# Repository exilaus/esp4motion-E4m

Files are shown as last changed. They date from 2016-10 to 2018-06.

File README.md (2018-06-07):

# esp4motion-E4m
killed

go to helping :
https://github.com/ryannining/karyacontroller

regards

old info.

This project want use D1 mini as basilar brain for Plotters lasercut cnc 3d printers.
currently in wip based from marginallyclever code portin on esp by Misan 

project currently managed by:
-Misan (Miguel sanchez)
-Exilaus (mauro manco)
-Darkberg (alex)

:) first preview set of board ordered....soon some news

Some info on board:
https://docs.google.com/presentation/d/1Ur_RV33AqiUAMNY1md2GBHKGxP4hxiyhX0XLN1OoxBo/edit?usp=sharing

First test of Misan
https://www.youtube.com/watch?v=iX7SKLwmQTw

For any info you can contact myself on G+ :) after test basic function on board need more coder :)

enjoy

Lib for arduino:

- https://github.com/tzapu/WiFiManager
- https://github.com/hibikiledo/Adafruit-MCP23017-Arduino-Library

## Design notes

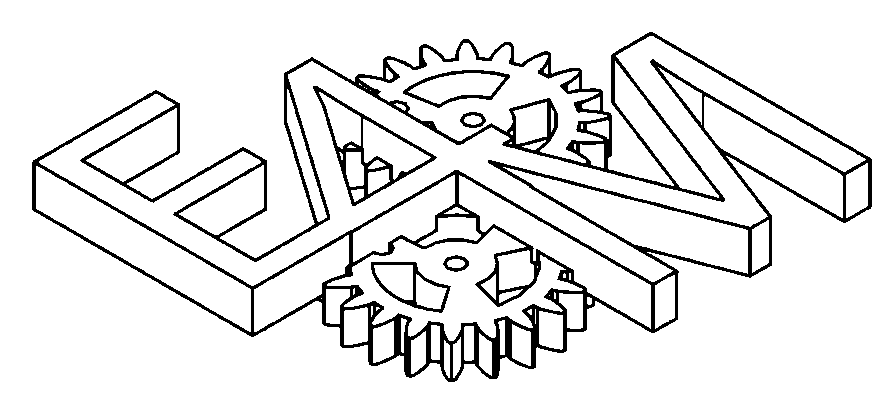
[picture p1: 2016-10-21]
board/e4m.bmp

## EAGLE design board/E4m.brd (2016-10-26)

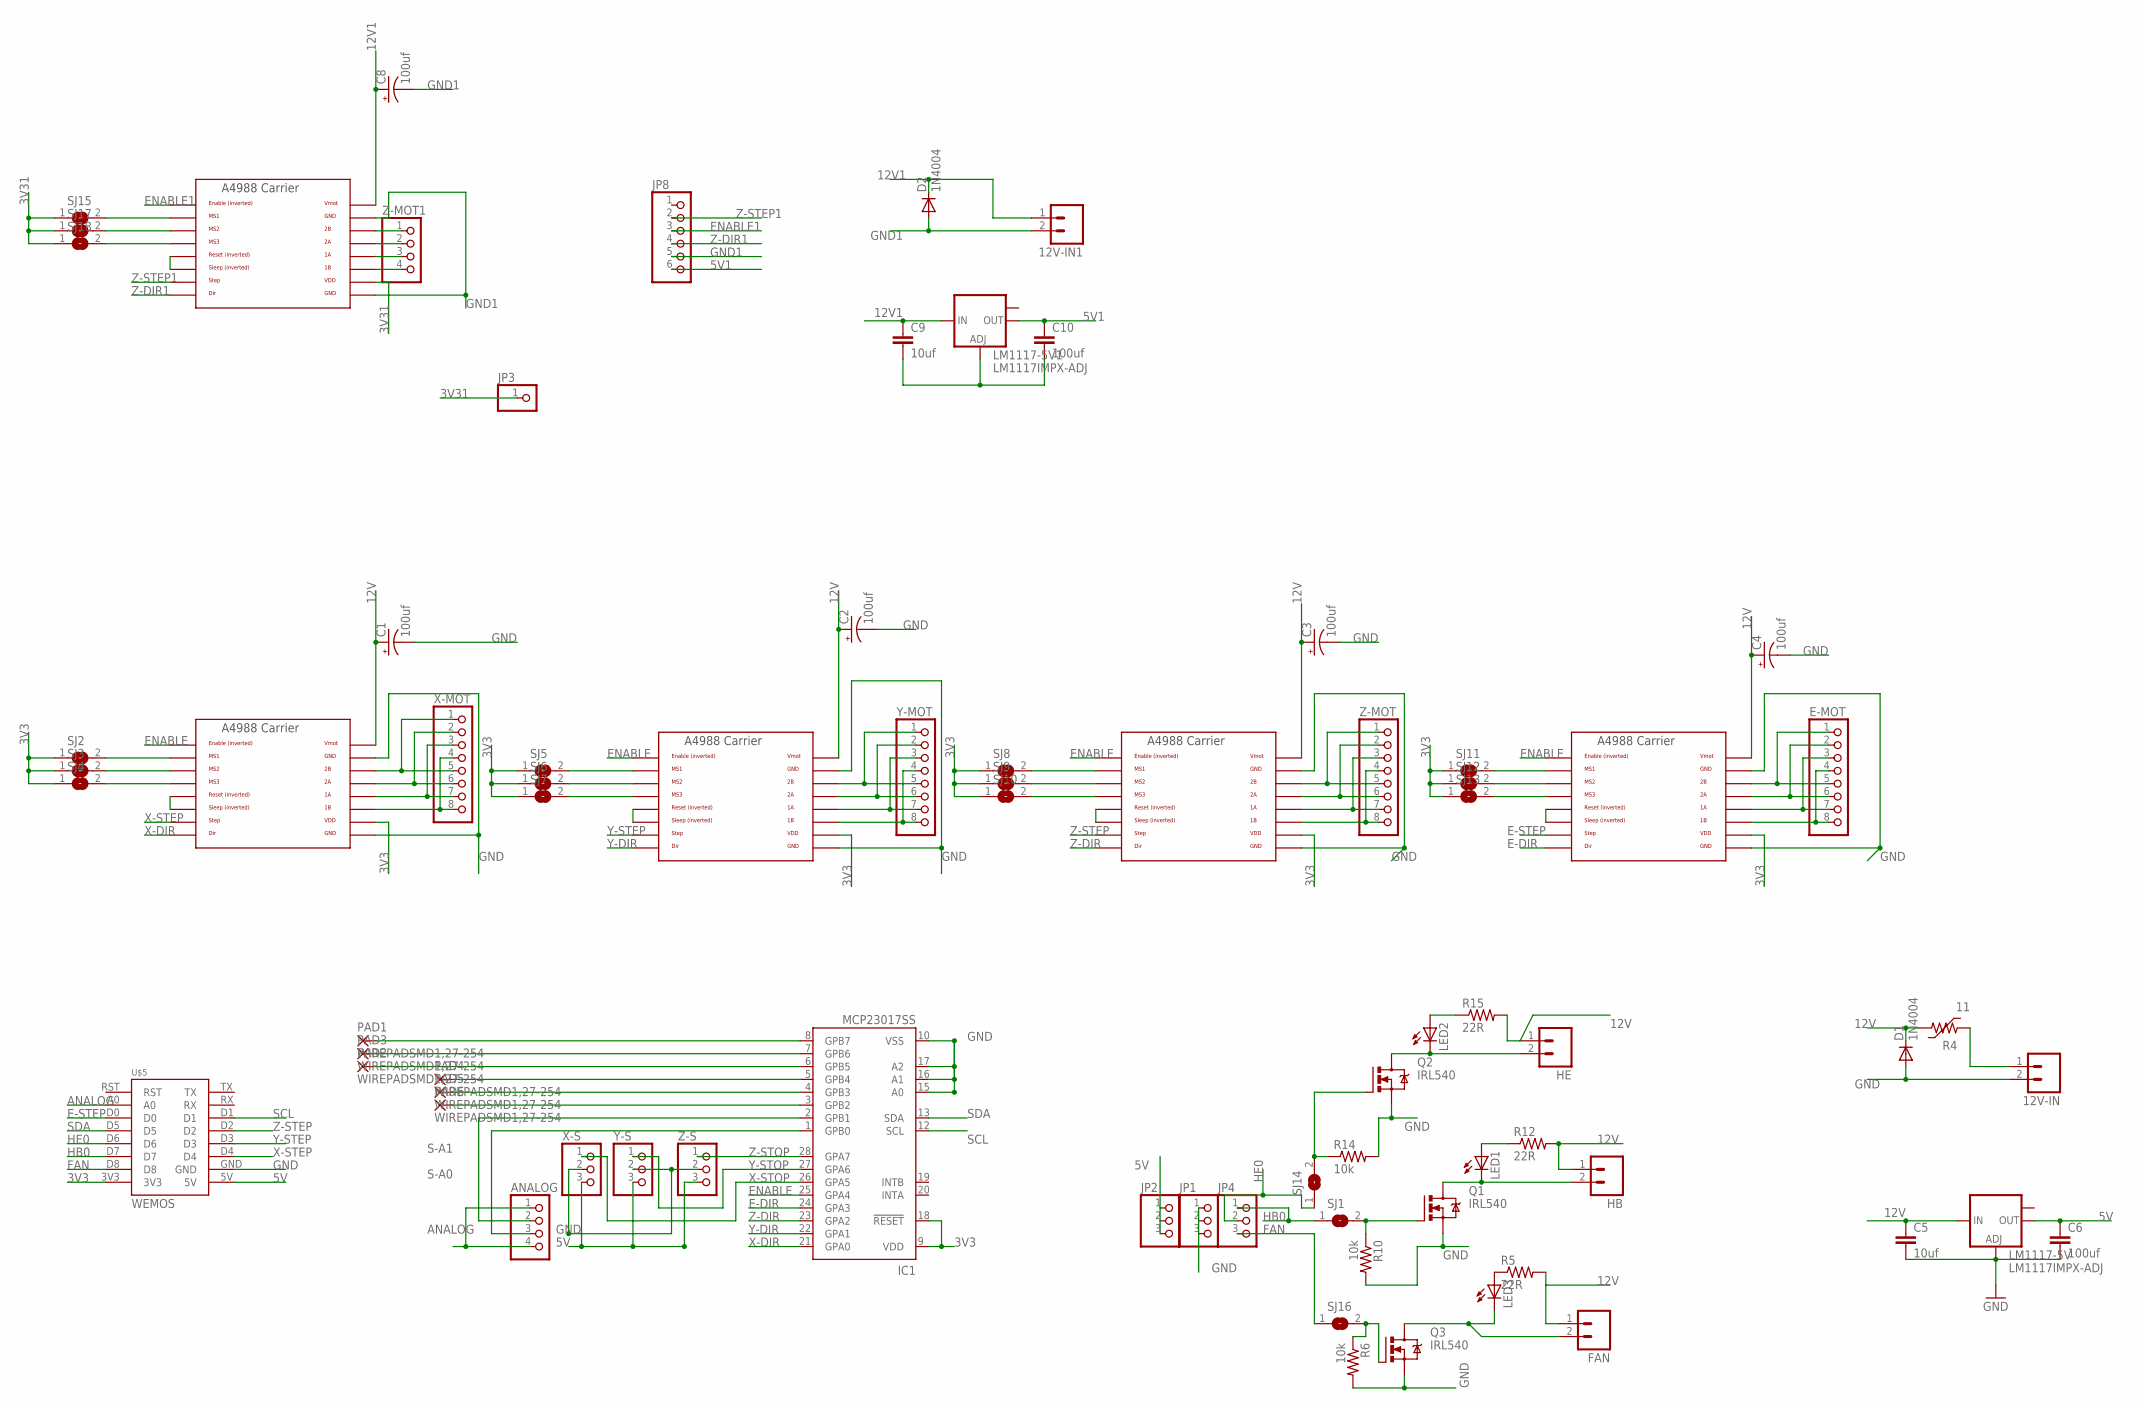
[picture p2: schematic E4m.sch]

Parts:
12V-IN, 12V-IN1: M02PTH; 1X02
ANALOG: PINHD-1X4; 1X04
C1, C2, C3, C4, C8: 100uf; 153CLV-0605
C5: 10uf; C0805
C6: 100uf; C0805
C9: 10uf; C0603
C10: 100uf; C0603
D1, D2: 1N4004; DO41-10
E-MOT: PINHD-1X8CLEANBIG; 1X08-CLEANBIG
FAN: M02PTH; 1X02
HB: M02PTH; 1X02
HE: M02PTH; 1X02
IC1: MCP23017SS; SSOP28
JP1, JP2, JP4: PINHD-1X3CB; 1X03-CLEANBIG
JP3: PINHD-1X1CB; 1X01-CLEANBIG
JP8: PINHD-1X6; 1X06
LED1, LED2, LED3: LEDCHIP-LED0805; CHIP-LED0805
LM1117-5V, LM1117-5V1: LM1117IMPX-ADJ; SOT223
PAD1, PAD2, PAD3, PAD4, PAD5, PAD6: WIREPADSMD1,27-254; SMD1,27-2,54
Q1, Q2, Q3: IRL540; TO220BV
R4: 11; PF-8.0
R5, R12, R15: 22R; R0805
R6, R10, R14: 10k; R0805
SJ1, SJ2, SJ3, SJ4, SJ5, SJ6, SJ7, SJ8, SJ9, SJ10, SJ11, SJ12, SJ13, SJ14, SJ15, SJ16, SJ17, SJ18: SJ
U$1, U$2, U$3, U$6, U$9: A4988BREAKOUT
U$5: WEMOS
X-MOT: PINHD-1X8CLEANBIG; 1X08-CLEANBIG
X-S: PINHD-1X3CB; 1X03-CLEANBIG
Y-MOT: PINHD-1X8CLEANBIG; 1X08-CLEANBIG
Y-S: PINHD-1X3CB; 1X03-CLEANBIG
Z-MOT: PINHD-1X8CLEANBIG; 1X08-CLEANBIG
Z-MOT1: PINHD-1X4; 1X04
Z-S: PINHD-1X3CB; 1X03-CLEANBIG

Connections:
3V3: IC1.9 (VDD), IC1.18 (!RESET), SJ2.1, SJ3.1, SJ4.1, SJ5.1, SJ6.1, SJ7.1, SJ8.1, SJ9.1, SJ10.1, SJ11.1, SJ12.1, SJ13.1, U$1.VDD, U$2.VDD, U$3.VDD, U$5.3V3, U$9.VDD
3V31: JP3.1, SJ15.1, SJ17.1, SJ18.1, U$6.VDD
5V: C6.1, JP2.1, JP2.2, JP2.3, LM1117-5V.2 (OUT), U$5.5V, X-S.3, Y-S.3, Z-S.3
5V1: C10.1, JP8.6, LM1117-5V1.2 (OUT)
12V: C1.+, C2.+, C3.+, C4.+, C5.1, D1.C, FAN.1, HB.1, HE.1, LM1117-5V.3 (IN), R4.2, R5.2, R12.2, R15.2, U$1.VMOT, U$2.VMOT, U$3.VMOT, U$9.VMOT
12V1: 12V-IN1.1, C8.+, C9.1, D2.C, LM1117-5V1.3 (IN), U$6.VMOT
ANALOG: ANALOG.1, ANALOG.4, U$5.A0
AUX2: IC1.8 (GPB7), PAD1.1
E-DIR: IC1.24 (GPA3), U$2.DIR
E-STEP: U$2.STEP, U$5.D0
ENABLE: IC1.25 (GPA4), U$1.EN, U$2.EN, U$3.EN, U$9.EN
ENABLE1: JP8.3, U$6.EN
FAN: JP4.3, SJ16.1, U$5.D8
GND: 12V-IN.2, C1.-, C2.-, C3.-, C4.-, C5.2, C6.2, D1.A, IC1.10 (VSS), IC1.15 (A0), IC1.16 (A1), IC1.17 (A2), JP1.1, JP1.2, JP1.3, LM1117-5V.1 (ADJ), Q1.S, Q2.S, Q3.S, R6.2, R10.2, R14.2, U$1.GND, U$1.GND@0 (GND), U$2.GND, U$2.GND@0 (GND), U$3.GND, U$3.GND@0 (GND), U$5.GND, U$9.GND, U$9.GND@0 (GND), X-S.2, Y-S.2, Z-S.2
GND1: 12V-IN1.2, C8.-, D2.A, JP8.5, U$6.GND, U$6.GND@0 (GND)
HB0: JP4.1, SJ1.1, U$5.D7
HE0: JP4.2, SJ14.1, U$5.D6
unnamed: LED3.A, R5.1
unnamed: IC1.7 (GPB6), PAD3.1
unnamed: SJ12.2, U$2.MS2
unnamed: U$2.RST, U$2.SLP (SLEEP)
unnamed: SJ13.2, U$2.MS3
unnamed: SJ11.2, U$2.MS1
unnamed: U$3.1B, Y-MOT.4, Y-MOT.8
unnamed: U$3.1A, Y-MOT.3, Y-MOT.7
unnamed: U$3.2A, Y-MOT.2, Y-MOT.6
unnamed: U$3.2B, Y-MOT.1, Y-MOT.5
unnamed: U$1.1B, X-MOT.4, X-MOT.8
unnamed: HB.2, LED1.C, Q1.D
unnamed: U$1.1A, X-MOT.3, X-MOT.7
unnamed: U$1.2A, X-MOT.2, X-MOT.6
unnamed: U$1.2B, X-MOT.1, X-MOT.5
unnamed: U$9.1B, Z-MOT.4, Z-MOT.8
unnamed: FAN.2, LED3.C, Q3.D
unnamed: IC1.3 (GPB2), PAD6.1
unnamed: U$9.1A, Z-MOT.3, Z-MOT.7
unnamed: IC1.6 (GPB5), PAD2.1
unnamed: IC1.5 (GPB4), PAD4.1
unnamed: Q2.G, R14.1, SJ14.2
unnamed: SJ3.2, U$1.MS2
unnamed: U$9.RST, U$9.SLP (SLEEP)
unnamed: IC1.4 (GPB3), PAD5.1
unnamed: Q3.G, R6.1, SJ16.2
unnamed: U$3.RST, U$3.SLP (SLEEP)
unnamed: U$1.RST, U$1.SLP (SLEEP)
unnamed: 12V-IN.1, R4.1
unnamed: SJ4.2, U$1.MS3
unnamed: SJ2.2, U$1.MS1
unnamed: SJ17.2, U$6.MS2
unnamed: SJ18.2, U$6.MS3
unnamed: SJ15.2, U$6.MS1
unnamed: U$6.2B, Z-MOT1.1
unnamed: U$6.2A, Z-MOT1.2
unnamed: U$6.1A, Z-MOT1.3
unnamed: U$6.1B, Z-MOT1.4
unnamed: U$6.RST, U$6.SLP (SLEEP)
unnamed: U$9.2A, Z-MOT.2, Z-MOT.6
unnamed: U$9.2B, Z-MOT.1, Z-MOT.5
unnamed: C9.2, C10.2, LM1117-5V1.1 (ADJ)
unnamed: E-MOT.4, E-MOT.8, U$2.1B
unnamed: E-MOT.3, E-MOT.7, U$2.1A
unnamed: LED1.A, R12.1
unnamed: E-MOT.2, E-MOT.6, U$2.2A
unnamed: SJ6.2, U$3.MS2
unnamed: HE.2, LED2.C, Q2.D
unnamed: SJ7.2, U$3.MS3
unnamed: SJ5.2, U$3.MS1
unnamed: E-MOT.1, E-MOT.5, U$2.2B
unnamed: SJ9.2, U$9.MS2
unnamed: LED2.A, R15.1
unnamed: SJ10.2, U$9.MS3
unnamed: SJ8.2, U$9.MS1
N$S4: Q1.G, R10.1, SJ1.2
S-A0: ANALOG.3, IC1.1 (GPB0)
S-A1: ANALOG.2, IC1.2 (GPB1)
SCL: IC1.12 (SCL), U$5.D1
SDA: IC1.13 (SDA), U$5.D5
X-DIR: IC1.21 (GPA0), U$1.DIR
X-STEP: U$1.STEP, U$5.D4
X-STOP: IC1.26 (GPA5), X-S.1
Y-DIR: IC1.22 (GPA1), U$3.DIR
Y-STEP: U$3.STEP, U$5.D3
Y-STOP: IC1.27 (GPA6), Y-S.1
Z-DIR: IC1.23 (GPA2), U$9.DIR
Z-DIR1: JP8.4, U$6.DIR
Z-STEP: U$5.D2, U$9.STEP
Z-STEP1: JP8.2, U$6.STEP
Z-STOP: IC1.28 (GPA7), Z-S.1

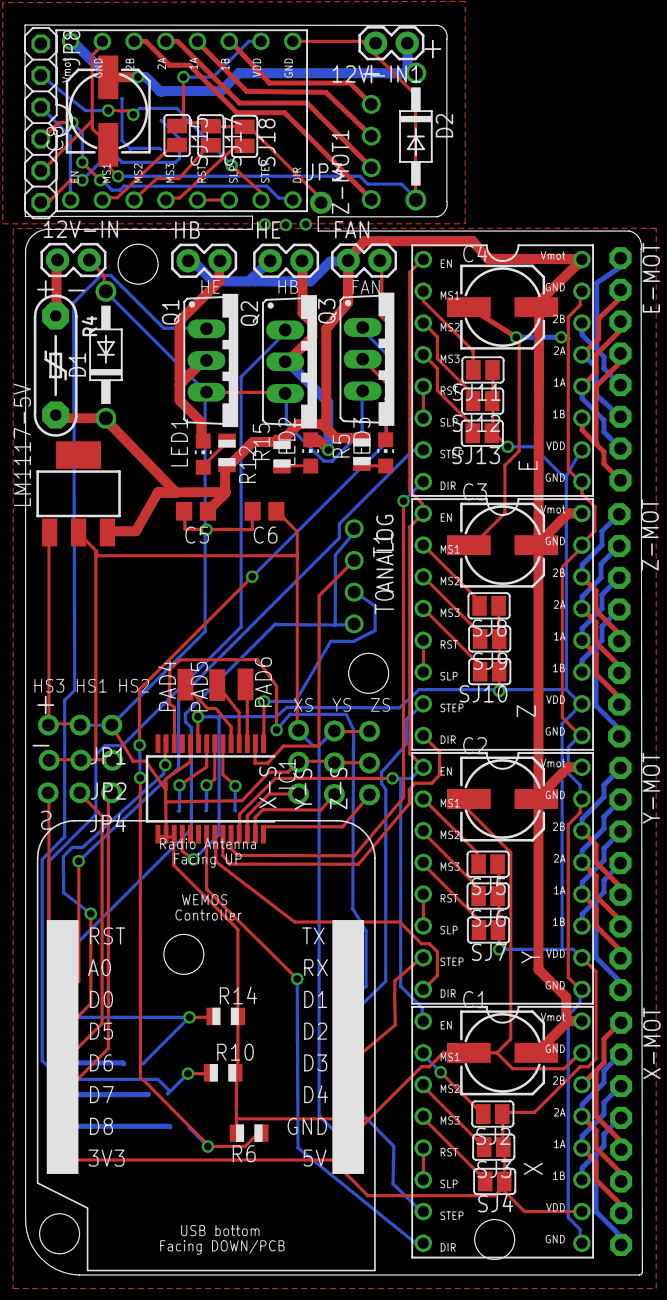
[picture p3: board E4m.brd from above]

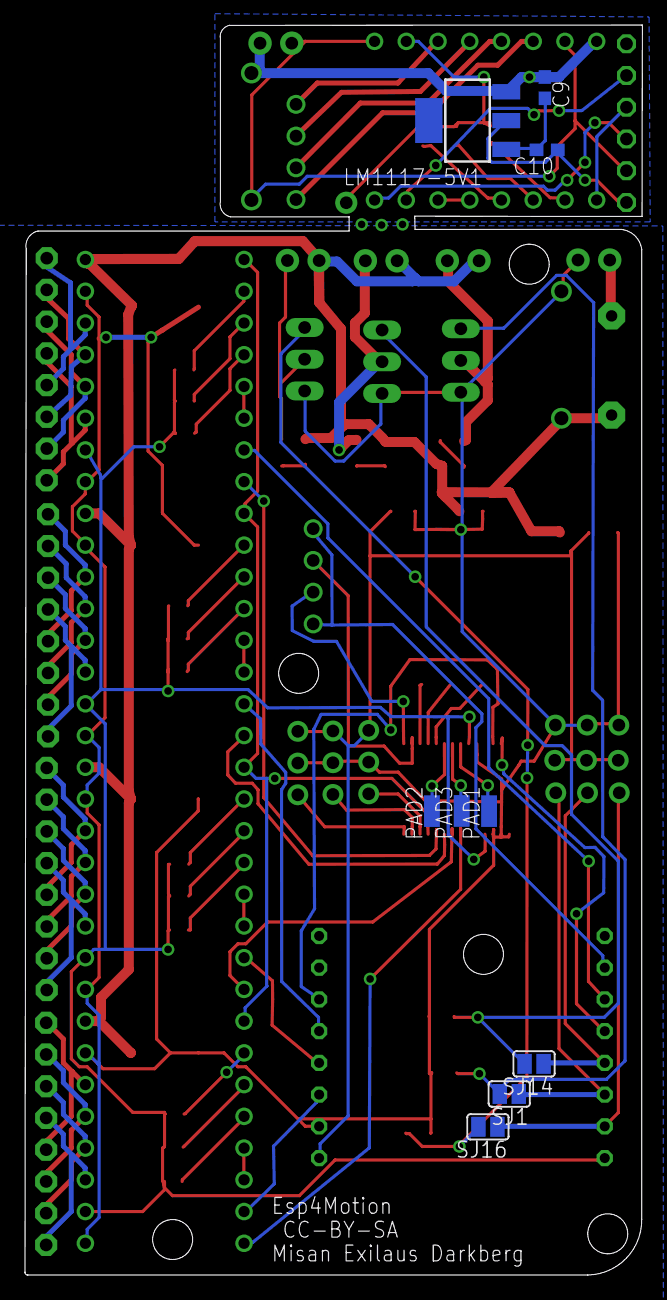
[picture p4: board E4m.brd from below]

Board: 2 copper layers, 49.4 x 100.1 mm, 76 parts (9 on the bottom side), 88 nets.

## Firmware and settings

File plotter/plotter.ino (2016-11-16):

/* ---------------------------------
 * Controls 2 steppers with ESP8266 and CNC shield plus one server on Z step 
 * for 4xiDraw machine  and Esp4motion board.
 *  
 * Code by misan,exilaus October 2016
 * known to work on Wemos D1 board 
 *  
 * both serial 115200 and UDP 9999 accept g-code 
 * 
 * 
 * Based on original work of dan@marginallycelver.com 2013-08-30 http://www.github.com/MarginallyClever/GcodeCNCDemo
 * cc-by-sa
 */  

  /*   PIN Esp4motion board */
#define xstep (2)
#define xdir (0)  //on mcp23017
#define xstop (5) //on mcp23017
#define ystep (0)
#define ydir (1)  //on mcp23017
#define ystop (6) //on mcp23017
#define zstep (4)
#define zdir (2)  //on mcp23017
#define zstop (7) //on mcp23017
#define estep (16) //on mcp23017 
#define edir (3)  //on mcp23017
#define En   (4)  //on mcp23017
#define hs1 (12)  //heathead or servo
#define hs2 (13)  //heatbed  or servo
#define hs3 (15)  //fan      or servo
#define SDA (15)  //to mcp23017
#define SDC (5)  //to mcp23017
 
#define VERSION        (1)  // firmware version
#define MAX_BUF        (64)  // What is the longest message Arduino can store?


// for arc directions
#define ARC_CW          (1)
#define ARC_CCW         (-1)
// Arcs are split into many line segments.  How long are the segments?
#define MM_PER_SEGMENT  (1)

#include "userscfg.h"



#include <ESP8266WiFi.h>
#include <WiFiManager.h> 
#include <DNSServer.h>
#include <WiFiUdp.h>
#include <WiFiClient.h>
#include <WiFiServer.h>
#include <Wire.h>
#include <Adafruit_MCP23017.h>

Adafruit_MCP23017 mcp;

const char* SSID_NAME = "ESP8266AP";  // WiFi AP SSID Name
const char* SSID_PASS = "0123456789"; // WiFi AP SSID Password
unsigned int localPort = 9999;
WiFiServer server(9999);
WiFiClient client;
WiFiUDP port;

int ACCEL =    1500 ;  // mm/s^2
boolean flip = false;
int i = 1;
long last=0;
int servo=1500;
float factor, v2 = 0;


// interrupt triggered by timer expiring
// motion will happen here based on a few variables
volatile int cs=0; // current step
long accel_steps=1000; // how many steps during acceleration
long coast_steps=40000; // how many steps during coasting
long total_steps=0; // total number of steps for the current movement
float t0=0.1;   // determines initial speed
float cn;
boolean diry,dirx;
long over;
float dx,dy;

volatile boolean busy = false;


void itr1(void) {
  if(flip) {
    digitalWrite(hs1,LOW);
    flip = false;
    timer1_write(20000 * 5); // 20 ms between pulses
  }
  else {
    timer1_write(servo*5);
    flip = true;
    digitalWrite(hs1,HIGH);
  }
}

void itr (void) {
  if( cs >= total_steps ) {busy = false; timer0_write(ESP.getCycleCount() + 80000000L/100);  } // no more interrupts scheduled
  else { // I have to move the motors
    cs++;
    if( cs < accel_steps ) {
      // acceleration
      cn = cn - (cn*2)/(4*cs+1);
      //Serial.println(cn);
    }
    else if ( cs < accel_steps + coast_steps ) {
    // coast at max speed
    }
    else if(cs<total_steps) {
      // decceleration
      cn = cn - (cn*2)/(4*(cs-total_steps)+1); 
      //Serial.println(cn);
    }
    
    timer0_write(ESP.getCycleCount() + (long) (20000000L*cn) );  // schedule next pulse

    if(dx>dy) {
      digitalWrite(xstep, HIGH);
      over+=dy;
      if(over>=dx) {
        over-=dx;
        digitalWrite(ystep, HIGH);
      }
      delayMicroseconds(1);
    } else {
      digitalWrite(ystep, HIGH);
      over+=dx;
      if(over>=dy) {
        over-=dy;
        digitalWrite(xstep, HIGH);
      }
      delayMicroseconds(1);
  }
  digitalWrite(ystep, LOW);
  digitalWrite(xstep , LOW);   
  } 
}



//------------------------------------------------------------------------------
// GLOBALS
//------------------------------------------------------------------------------

char buffer[MAX_BUF];  // where we store the message until we get a newline
int sofar;  // how much is in the buffer

float px, py;  // location

// speeds
float fr=1000;  // human version
long step_delay;  // machine version

// settings
char mode_abs=1;  // absolute mode?


//------------------------------------------------------------------------------
// METHODS
//------------------------------------------------------------------------------


/**
 * delay for the appropriate number of microseconds
 * @input ms how many milliseconds to wait
 */
void pause(long ms) {
  delay(ms/1000);
  delayMicroseconds(ms%1000);  // delayMicroseconds doesn't work for values > ~16k.
}


/**
 * Set the feedrate (speed motors will move)
 * @input nfr the new speed in steps/second
 */
void feedrate(float nfr) {
  if(fr==nfr) return;  // same as last time?  quit now.
  if(nfr>MAX_FEEDRATE || nfr<MIN_FEEDRATE) {  // don't allow crazy feed rates
    Serial.print(F("New feedrate must be greater than "));
    Serial.print(MIN_FEEDRATE);
    Serial.print(F("steps/s and less than "));
    Serial.print(MAX_FEEDRATE);
    Serial.println(F("steps/s."));
    return;
  }
  step_delay = 1000000.0/nfr;
  fr=nfr;
  cn = t0 = sqrt( 2.0 /** STEPS_MM*/ / ACCEL );
}


/**
 * Set the logical position
 * @input npx new position x
 * @input npy new position y
 */
void position(float npx,float npy) {
  // here is a good place to add sanity tests
  px=npx;
  py=npy;
}

//#define max(a,b) ((a)>(b)?(a):(b))

/**
 * Uses bresenham's line algorithm to move both motors
 * @input newx the destination x position
 * @input newy the destination y position
 **/
void line(float newx,float newy) {
  dx=newx-px;
  dy=newy-py;
  dirx=dx>0;
  diry=dy>0;  // because the motors are mounted in opposite directions
  dx=abs(dx);
  dy=abs(dy);
// Serial.print("line: ");Serial.print(dx); Serial.print(","); Serial.println(dy);
//  move(dx,dirx,dy,diry);
  long i;
  over=0;

  total_steps = _max ( dx, dy ) * STEPS_MMX; 
  float ta = fr / 60.0 / ACCEL;
  float ea = ( fr / 60.0 ) * ta / 2 ;
  accel_steps = _min(ea * STEPS_MMX , total_steps/2); // just in case feedrate cannot be reached 
  coast_steps = total_steps - accel_steps * 2; // acceleration
  mcp.digitalWrite(0, dirx); // direction of X motor
  mcp.digitalWrite(1, diry);
  cs = 0; // let the motion start :-)
  cn = t0;

  if(dx>dy) over=dx/2; else over=dy/2;
  busy=true;
  // wait till the command ends
  while(busy) { /*doServo();*/

                delay(0); }
  px=newx;
  py=newy;
}


// returns angle of dy/dx as a value from 0...2PI
float atan3(float dy,float dx) {
  float a=atan2(dy,dx);
  if(a<0) a=(PI*2.0)+a;
  return a;
}


// This method assumes the limits have already been checked.
// This method assumes the start and end radius match.
// This method assumes arcs are not >180 degrees (PI radians)
// cx/cy - center of circle
// x/y - end position
// dir - ARC_CW or ARC_CCW to control direction of arc
void arc(float cx,float cy,float x,float y,float dir) {
  // get radius
  float dx = px - cx;
  float dy = py - cy;
  float radius=sqrt(dx*dx+dy*dy);

  // find angle of arc (sweep)
  float angle1=atan3(dy,dx);
  float angle2=atan3(y-cy,x-cx);
  float theta=angle2-angle1;
  
  if(dir>0 && theta<0) angle2+=2*PI;
  else if(dir<0 && theta>0) angle1+=2*PI;
  
  theta=angle2-angle1;
  
  // get length of arc
  // float circ=PI*2.0*radius;
  // float len=theta*circ/(PI*2.0);
  // simplifies to
  float len = abs(theta) * radius;

  int i, segments = ceil( len * MM_PER_SEGMENT );
 
  float nx, ny, angle3, scale;

  for(i=0;i<segments;++i) {
    // interpolate around the arc
    scale = ((float)i)/((float)segments);
    
    angle3 = ( theta * scale ) + angle1;
    nx = cx + cos(angle3) * radius;
    ny = cy + sin(angle3) * radius;
    // send it to the planner
    line(nx,ny);
  }
  
  line(x,y);
}


/**
 * Look for character /code/ in the buffer and read the float that immediately follows it.
 * @return the value found.  If nothing is found, /val/ is returned.
 * @input code the character to look for.
 * @input val the return value if /code/ is not found.
 **/
float parsenumber(char code,float val) {
  char *ptr=buffer;
  while(ptr && *ptr && ptr<buffer+sofar) {
    if(*ptr==code) {
      return atof(ptr+1);
    }
    ptr++; //ptr=strchr(ptr,' ')+1;
  }
  return val;
} 


/**
 * write a string followed by a float to the serial line.  Convenient for debugging.
 * @input code the string.
 * @input val the float.
 */
void output(const char *code,float val) {
  Serial.print(code);
  Serial.println(val);
}


void findHome(int vel) {
 mcp.digitalWrite(xdir,LOW);
 mcp.digitalWrite(ydir,LOW);
 
 while(mcp.digitalRead(xstop) == LOW) {  digitalWrite(xstep, HIGH);
                                         delayMicroseconds(1);
                                         digitalWrite(xstep, LOW);
                                         delay(vel);
                                      }
 mcp.digitalWrite(xdir,HIGH); 
 for(i=0;i==STEPS_MMX;++i) {digitalWrite(xstep, HIGH);
                           delayMicroseconds(1);
                           digitalWrite(xstep, LOW);
                          } 
                                   
                                                                  
                                       
  while(mcp.digitalRead(ystop) == LOW){  digitalWrite(ystep, HIGH);
                                         delayMicroseconds(vel);
                                         digitalWrite(ystep, LOW);
                                         delay(vel);
                                      }  
  mcp.digitalWrite(ydir,HIGH); 
  for(i=0;i==STEPS_MMY;++i) {digitalWrite(ystep, HIGH);
                            delayMicroseconds(1);
                            digitalWrite(ystep, LOW);
                           } 
  if (vel!= 100)  { findHome(100);} 
  px=0;
  py=0;
                                       
}



/**
 * print the current position, feedrate, and absolute mode.
 */
void where() {
  output("X",px);
  output("Y",py);
  output("F",fr);
  Serial.println(mode_abs?"ABS":"REL");
} 


/**
 * display helpful information
 */
void help() {
  Serial.print(F("GcodeCNCDemo2AxisV1 "));
  Serial.println(VERSION);
  Serial.println(F("Commands:"));
  Serial.println(F("G00 [X(steps)] [Y(steps)] [F(feedrate)]; - line"));
  Serial.println(F("G01 [X(steps)] [Y(steps)] [F(feedrate)]; - line"));
  Serial.println(F("G02 [X(steps)] [Y(steps)] [I(steps)] [J(steps)] [F(feedrate)]; - clockwise arc"));
  Serial.println(F("G03 [X(steps)] [Y(steps)] [I(steps)] [J(steps)] [F(feedrate)]; - counter-clockwise arc"));
  Serial.println(F("G04 P[seconds]; - delay"));
  Serial.println(F("G90; - absolute mode"));
  Serial.println(F("G91; - relative mode"));
  Serial.println(F("G92 [X(steps)] [Y(steps)]; - change logical position"));
  Serial.println(F("M3 SXXX; - 0-255 pwm signal on hs1"));
  Serial.println(F("M5 ; - stop hs1"));
  Serial.println(F("M18; - disable motors"));
  Serial.println(F("M100; - this help message"));
  Serial.println(F("M114; - report position and feedrate"));
  Serial.println(F("All commands must end with a newline."));
  // Print the IP address
  Serial.print("Use this URL to connect: http://");
  Serial.print(WiFi.softAPIP());
  Serial.print(':');
  Serial.print(localPort);
  Serial.println('/');
}


/**
 * Read the input buffer and find any recognized commands.  One G or M command per line.
 */
void processCommand() {
  int cmd = parsenumber('G',-1); 
  switch(cmd) {
  case  0:
  case  1: { // line
    feedrate(parsenumber('F',fr));
    line( parsenumber('X',(mode_abs?px:0)) + (mode_abs?0:px),
          parsenumber('Y',(mode_abs?py:0)) + (mode_abs?0:py) );
    break;
    }
  case 2:
  case 3: {  // arc
      feedrate(parsenumber('F',fr));
      arc(parsenumber('I',(mode_abs?px:0)) + (mode_abs?0:px),
          parsenumber('J',(mode_abs?py:0)) + (mode_abs?0:py),
          parsenumber('X',(mode_abs?px:0)) + (mode_abs?0:px),
          parsenumber('Y',(mode_abs?py:0)) + (mode_abs?0:py),
          (cmd==2) ? -1 : 1);
      break;
    }
  case 28: {  // home
             findHome(1);
             break;
           }
  case  4:  pause(parsenumber('P',0)*1000);  break;  // dwell
  case 90:  mode_abs=1;  break;  // absolute mode
  case 91:  mode_abs=0;  break;  // relative mode
  case 92:  // set logical position
    position( parsenumber('X',0),
              parsenumber('Y',0) );
    break;
  default:  break;
  }

  cmd = parsenumber('M',-1); 
  switch(cmd) {
  case 3:servo =  map(parsenumber('S',0), 0, 255,MIN_SERVO, MAX_SERVO); break; // sets the servo value in microseconds, it only works while inside loop :-(
  case 5:servo = 0; break;
  case 18:  // disable motors
//    disable();
    break;
  case 100:  help();  break;
  case 114:  where();  break;
  case 201: ACCEL = parsenumber('A',0); feedrate(fr); Serial.print(ACCEL); break; // M201 A<accel> change acceleration
  default:  break;
  }
}


/**
 * prepares the input buffer to receive a new message and tells the serial connected device it is ready for more.
 */
void ready() {
  sofar=0;  // clear input buffer
  Serial.print(F(">"));  // signal ready to receive input
}




void setup() {
// set mcp27013

  mcp.begin(0,SDA,SDC);      // use default address 0

  //mcp.pinMode(0, OUTPUT);
  pinMode(xstep, OUTPUT); // D2 stepX
  mcp.pinMode(xdir, OUTPUT); // D13 dirX
  mcp.pinMode(En, OUTPUT); // D8 enable
  pinMode(ystep, OUTPUT); // D15 stepY
  mcp.pinMode(ydir, OUTPUT); // D12 dirY
  pinMode(hs1, OUTPUT);   // D14 servo
  mcp.pinMode(xstop,INPUT);
  mcp.pinMode(ystop,INPUT);
  
  mcp.digitalWrite(En, LOW);
  digitalWrite(hs1, LOW);

  WiFi.mode(WIFI_AP);
  WiFi.softAP(SSID_NAME, SSID_PASS);
  port.begin(localPort);

  Serial.begin(BAUD);  // open coms

  //  setup_controller();  
  position(0,0);  // set staring position
  feedrate((MAX_FEEDRATE + MIN_FEEDRATE)/2);  // set default speed

  help();  // say hello
  ready();

  
  noInterrupts();
  timer0_isr_init();
  timer0_attachInterrupt(itr);
  timer0_write(ESP.getCycleCount() +5000);

  timer1_isr_init();
  timer1_attachInterrupt(itr1);
  timer1_enable(TIM_DIV16, TIM_EDGE, TIM_SINGLE);
  timer1_write(servo*5);

  interrupts();
  server.begin(); // start TCP server
  
}


char c;
long lastping;

void loop() {
  /*
  int packetSize = port.parsePacket();
  if (packetSize) {
    int len = port.read(buffer, 255); sofar=len; 
    if (len > 0) buffer[len-1] = 0; 
    Serial.println(buffer);
    processCommand();
    port.beginPacket(port.remoteIP(),port.remotePort());
    port.write("ok\r\n");
    port.endPacket();
  }
  */

 if(millis()-lastping>5000 && !client) { // only till first client connects
  lastping=millis();
  port.beginPacket("255.255.255.255",9999);
  port.write("Anybody there?\r\n");
  port.endPacket();
 }
  
  while(Serial.available() > 0 ) {  // if something is available
    c=Serial.read();  // get it
    Serial.print(c);  // repeat it back so I know you got the message
    if(sofar<MAX_BUF-1) buffer[sofar++]=c;  // store it
    if((c=='\n') || (c == '\r')) {
      // entire message received
      buffer[sofar]=0;  // end the buffer so string functions work right
      Serial.print(F("\r\n"));  // echo a return character for humans
      if(sofar>3) {
                  busy=true;
                  processCommand();  // do something with the command
                  ready(); 
                  }
    } 
  } 
  if(server.hasClient()){
    client=server.available();  // it will destroy a previous connection !!!
    Serial.println("TCP Client accepted");
  }
  if(client && client.connected()) {
    while(client.available()>0) {// if data available,let's hope it is the full command
      buffer[sofar++]=(c=client.read()); Serial.print(c); 
      if((c=='\n') || (c == '\r')) {
        buffer[sofar]=0;
        busy=true;
        processCommand();  // do something with the command
        ready(); 
        client.println("ok");
      }
    }
  }
}

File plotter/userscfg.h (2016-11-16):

#define BAUD           (115200) 
#define STEPS_PER_TURN (400) --not used
#define STEPS_MMX      (80)
#define STEPS_MMY      (80)

#define MAX_FEEDRATE   (50000) 
#define MIN_FEEDRATE   (0.01)


#define MIN_SERVO (5)
#define MAX_SERVO (2400)

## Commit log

2016-10-17 before routing
    before routing
    [E4m.brd, E4m.sch]
2016-10-18 final?
    mini4motion esp4motion
    [E4m.brd]
2016-10-20 last verified
    [E4m.brd, E4m.sch]
2016-10-23 ops
    added servo output and panelized 100x100
    [E4m.brd, E4m.sch]
2016-10-25 correct issue
    need re-route add all smd as 0805
    [E4m.brd]
2016-10-25 another update
    [E4m.brd, E4m.sch]
2016-10-25 update git including software
    [E4m.brd, E4m.sch]
2016-10-25 100% routed..... to clean before raster...
    yup
    [E4m.brd]
2016-10-25 again
    again
    [E4m.brd]
2016-10-25 dark clean and add raster
    [E4m.brd]
2016-10-25 clean clean clean
    [E4m.brd]
2016-10-25 update more and more :(
    agrrr
    [E4m.brd, E4m.sch]
2016-10-25 software update
    make something same marlin....
    [configuration.h]
2016-10-25 ok...issue on git..
    [E4m.sch, E4masda.brd]
2016-10-26 last...
    start panellization
    [E4m100x100.brd]
2016-10-26 some fake code...
    studing https://github.com/iandouglas96/piPrint/tree/master/Server
    [Configuration.h]
2016-10-27 add plotter configuration
    changed pin header for d1 pin...need add mcp23017
    [configuration.h]
2016-10-31 homing xy
    basic homing

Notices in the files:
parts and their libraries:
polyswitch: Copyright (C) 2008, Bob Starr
